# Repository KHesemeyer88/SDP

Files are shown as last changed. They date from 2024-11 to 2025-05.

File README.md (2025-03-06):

# SDP
Everyone has their own branch. 
You only work in your own branch.
Main only gets updated once a week and requires approval.
To collaborate in between, merge with your collaborator's branch back and forth.
To change branches: git checkout main, git checkout origin/YourBranch, etc.
To merge changes your collaborator made: git merge origin/CollaboratorBranch, etc.
  -Then resolve any merge conflicts, sync changes.

To get yourself up to date with main:
  -git checkout main
  -git pull
  -git checkout origin/YourBranch
  -git merge main

To merge person A to person B
-person A has updates / new code

In old/out_of_date branch

git merge the_branch_with_updates

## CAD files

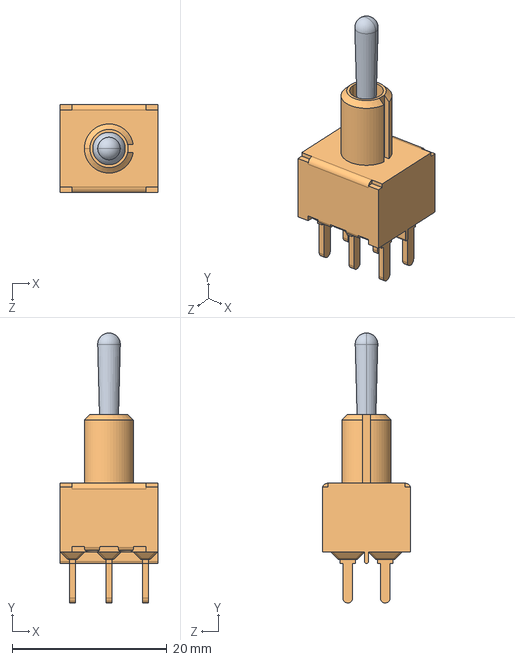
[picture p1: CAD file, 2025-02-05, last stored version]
powerDistribution/100DP3T1B1M2QEH.step
12.7 x 34.9 x 11.4 mm

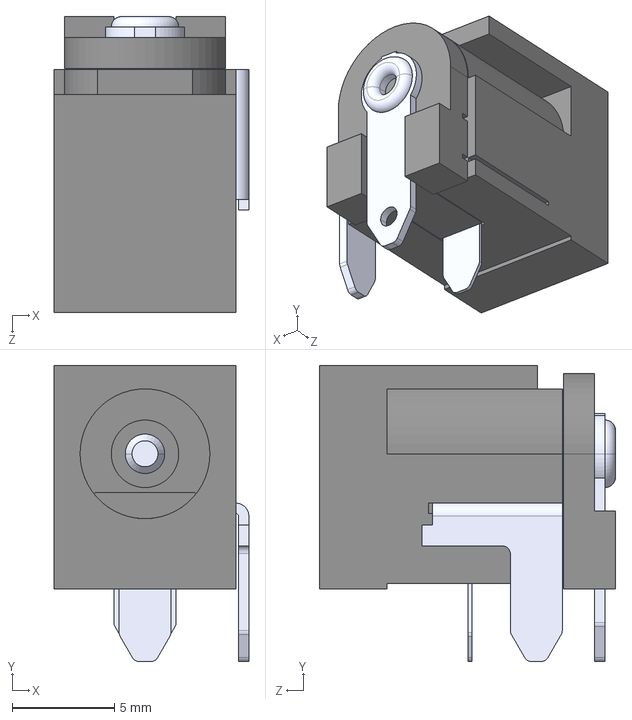
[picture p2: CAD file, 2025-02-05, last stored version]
powerDistribution/RAPC722X.step
9.53 x 14.5 x 14.5 mm

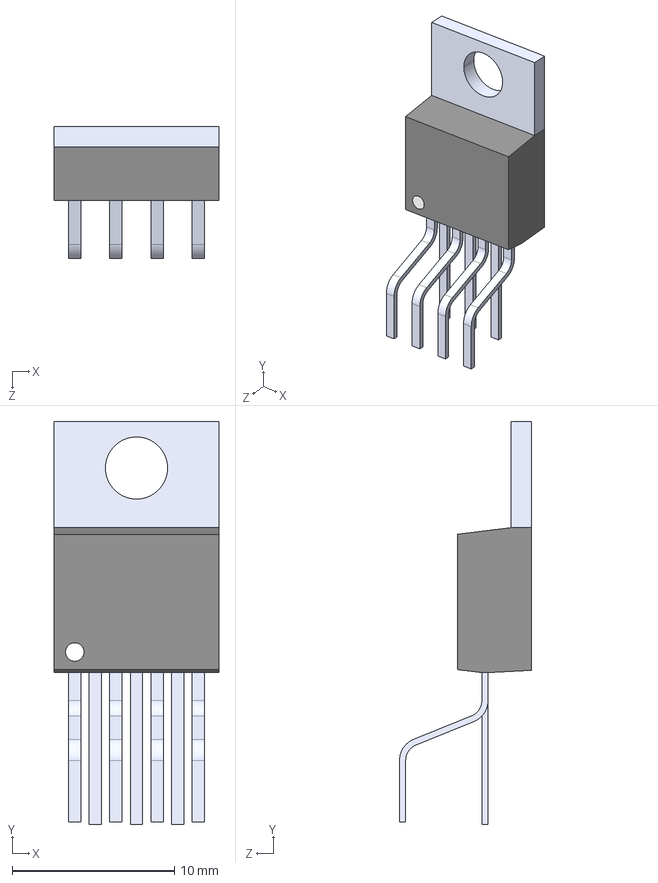
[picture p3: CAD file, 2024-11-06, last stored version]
powerDistribution/LM2678T-ADJ_NOPB.step
10.2 x 24.9 x 8.14 mm

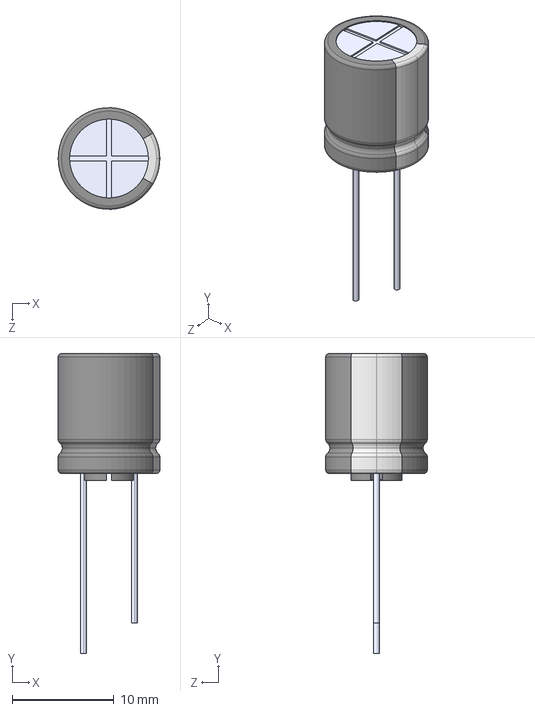
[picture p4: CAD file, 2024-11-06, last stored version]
powerDistribution/EEUFC1H101.step
10.0 x 29.5 x 9.99 mm

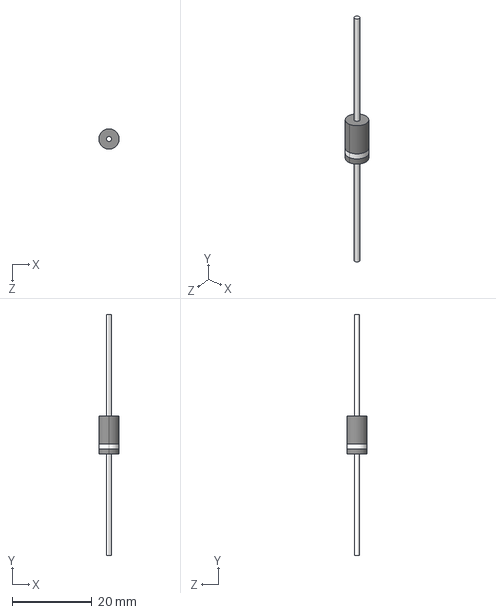
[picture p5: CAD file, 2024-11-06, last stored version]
powerDistribution/1N5822.step
5.08 x 60.3 x 5.08 mm

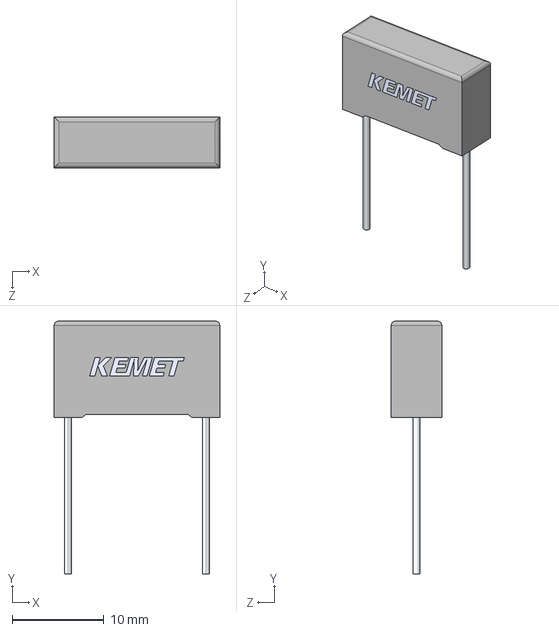
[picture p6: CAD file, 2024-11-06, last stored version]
powerDistribution/CFR_RB2_18X10.5X5.5_L18H10.5T5.5S15LL17F0.8.step
18.0 x 27.5 x 5.50 mm

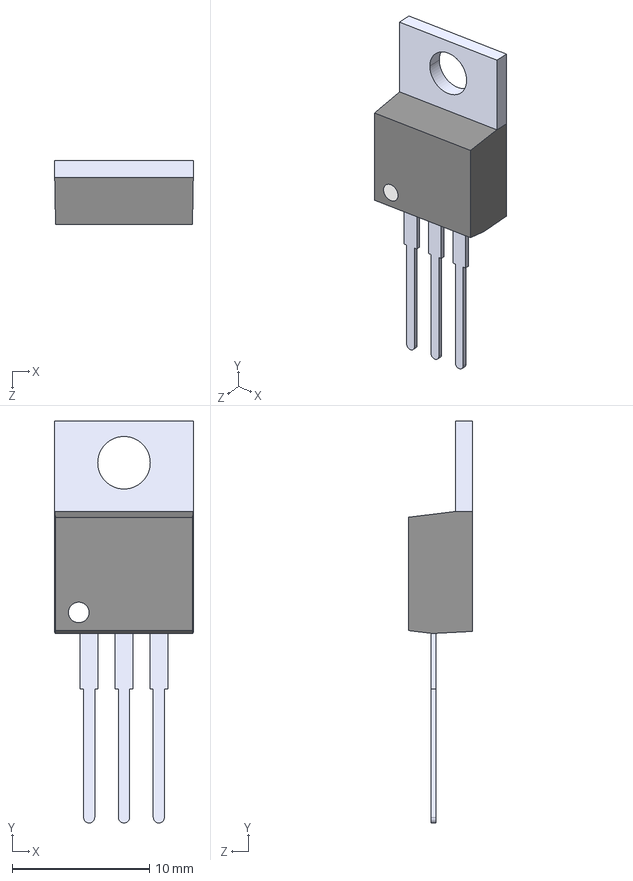
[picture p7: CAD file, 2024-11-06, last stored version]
powerDistribution/LM338T.step
10.2 x 29.3 x 4.70 mm

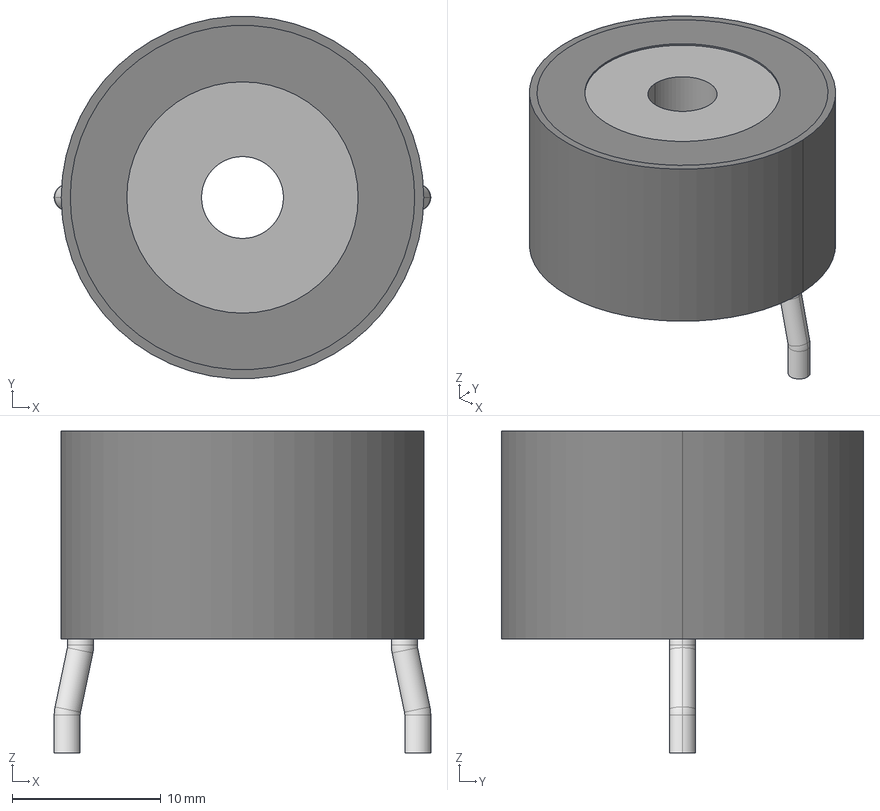
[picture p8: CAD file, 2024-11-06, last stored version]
powerDistribution/1410454C_MUR.step
25.4 x 24.4 x 21.7 mm

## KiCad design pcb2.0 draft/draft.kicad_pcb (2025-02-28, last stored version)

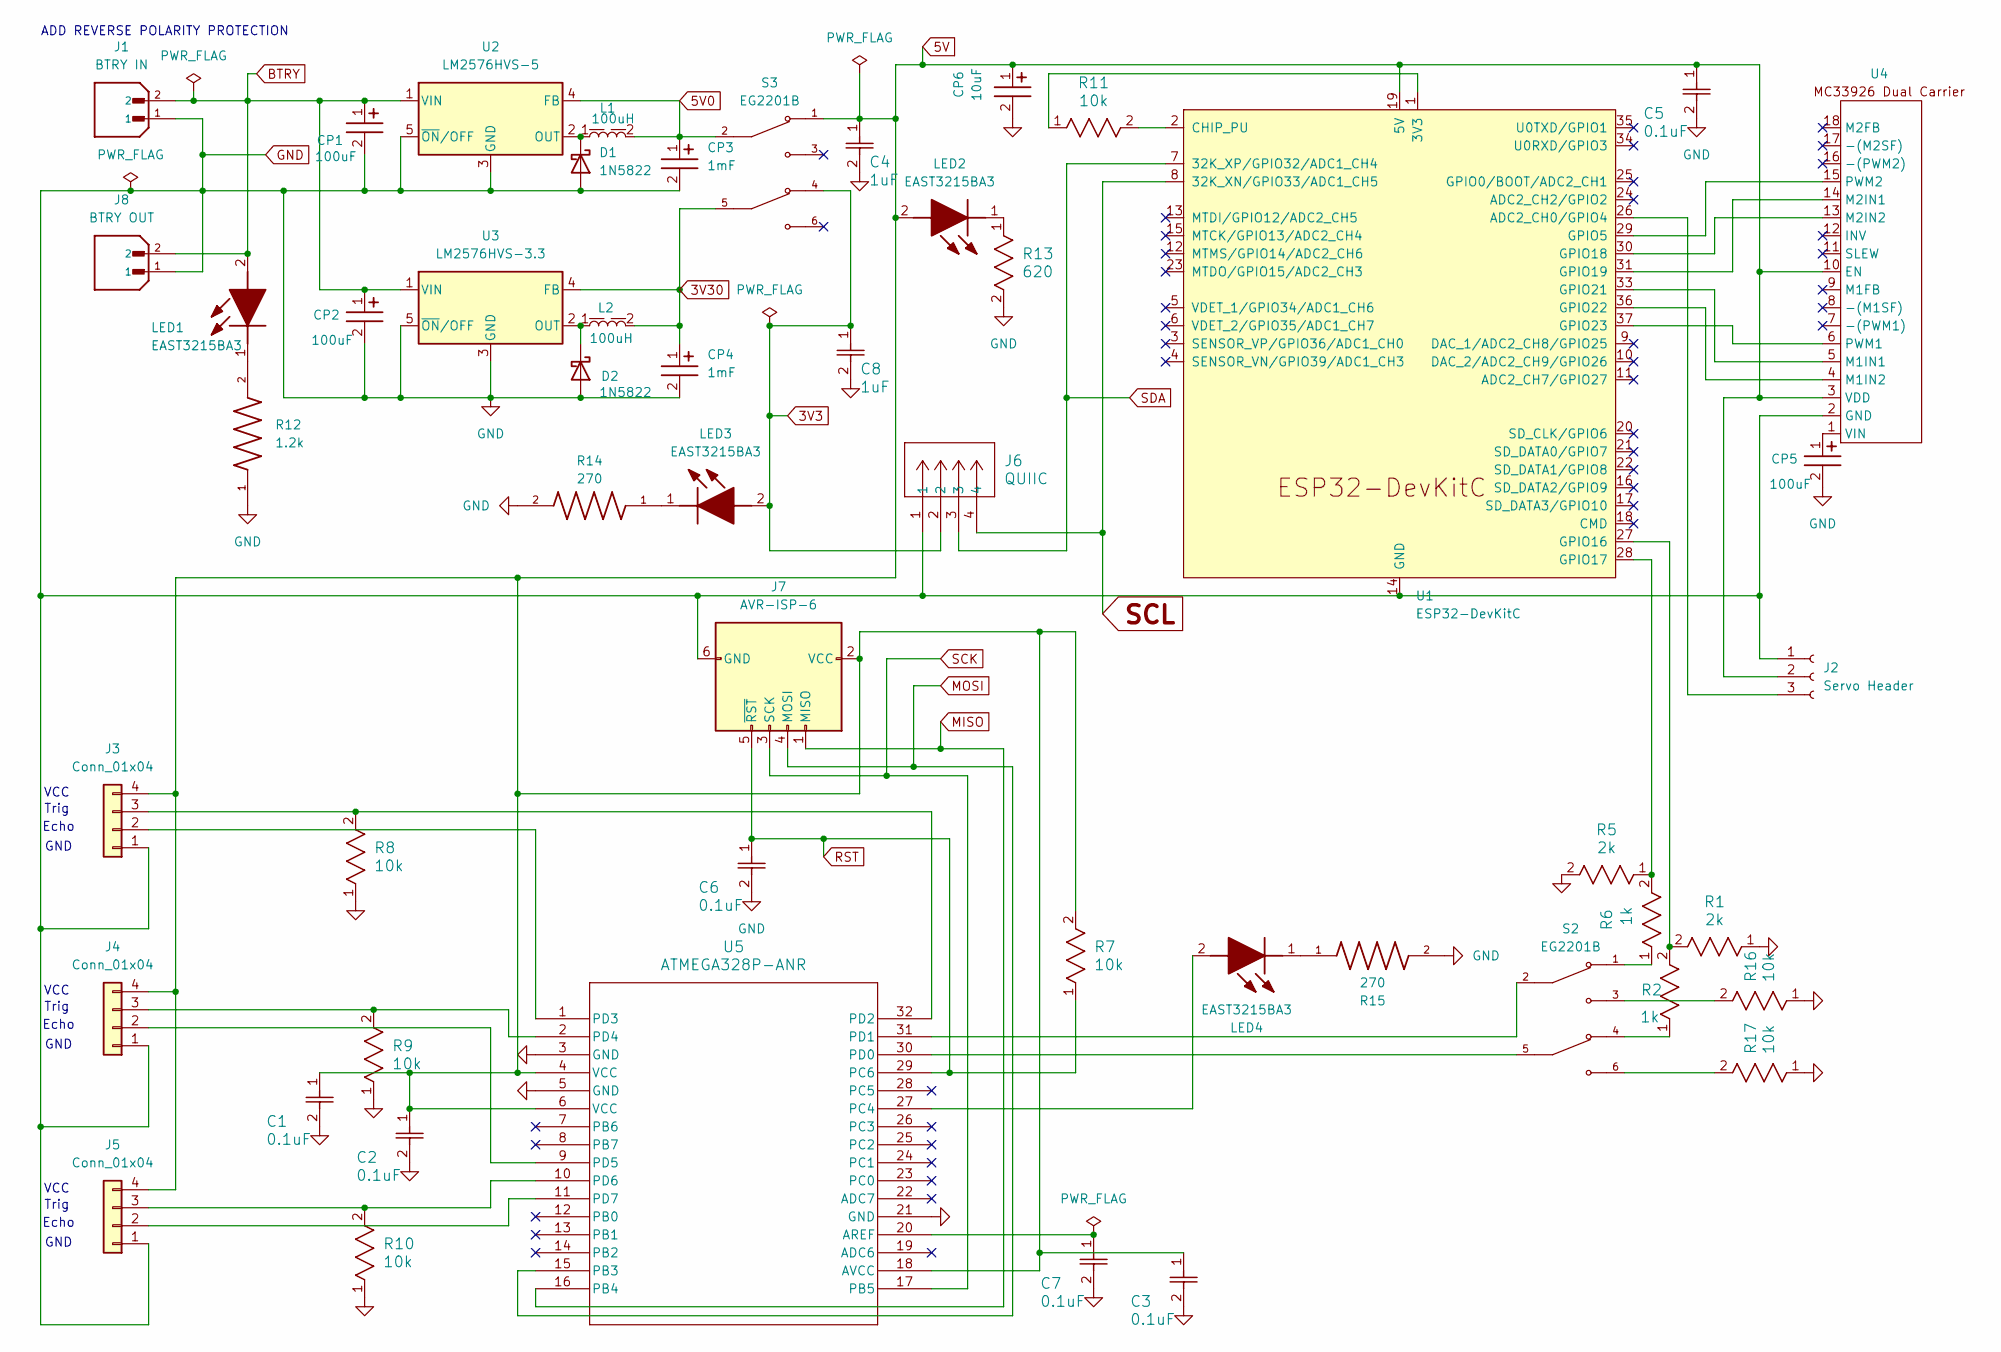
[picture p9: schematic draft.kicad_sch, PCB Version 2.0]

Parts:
C1, C2, C3, C5, C6, C7: 0.1uF; G-188_MUR-L
C4, C8: 1uF; CAP_GRM21_MUR-L
CP1, CP2, CP5: 100uF; CP_Wurth_WCAP-PSLP-D5L5.5; Part Number 875105242010
CP3, CP4: 1mF; CP_Wurth_WCAP-ASLI-D12.5L14; Part Number 865080462016
CP6: 10uF; CP_Wurth_WCAP-PSLP-D5L5.8; Part Number 875105359001
D1, D2: 1N5822; D_DO-201AD_P15.24mm_Horizontal
J1: BTRY IN; JST_B2B-XH-A; PARTREV N/A
J2: Servo Header; PinSocket_1x03_P2.54mm_Vertical
J3, J4, J5: Conn_01x04; PinHeader_1x04_P2.54mm_Vertical
J6: QUIIC; CONN_SM04B-SRSS-TB_JST
J7: AVR-ISP-6; IDC-Header_2x03_P2.54mm_Vertical
J8: BTRY OUT; JST_B2B-XH-A; PARTREV N/A
L1, L2: 100uH; L_Wurth_WE-PD-1245; Part Number 7447715101
LED1, LED2, LED3, LED4: EAST3215BA3; LEDC3215X110N; Mouser Part Number 638-EAST3215BA3
R1, R5: 2k; RES_CR0805_VEN-L
R2, R6: 1k; RES_CR0805_VEN-L
R7, R8, R9, R10, R11, R16, R17: 10k; RES_CR0805_VEN-L
R12: 1.2k; RES_ERJU08J122V; PARTREV 3/1/2020
R13: 620; RC1206N_PAN-L
R14, R15: 270; RES_ERJU08J271V; PARTREV 3/1/2020
S2, S3: EG2201B; SW_EG2201B; PARTREV C
U1: ESP32-DevKitC
U2: LM2576HVS-5; TO-263-5_TabPin3
U3: LM2576HVS-3.3; TO-263-5_TabPin3
U4: polulu_MC33926_dual
U5: ATMEGA328P-ANR; 32A_ATM-L

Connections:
3V3: C8.1, J6.2, LED3.2 (A), S3.4
3V30: CP4.1, L2.2, S3.5, U3.4 (FB)
5V: C1.1, C2.1, C3.1, C4.1, C5.1, CP6.1, J2.2, J3.4, J4.4, J5.4, J7.2 (VCC), LED2.2 (A), R7.2, S3.1, U1.19 (5V), U4.3 (VDD), U4.10 (EN), U5.4 (VCC), U5.6 (VCC), U5.18 (AVCC)
5V0: CP3.1, L1.2, S3.2, U2.4 (FB)
BTRY: CP1.1, CP2.1, J1.2, J8.2, LED1.2 (A), U2.1 (VIN), U3.1 (VIN)
GND: C1.2, C2.2, C3.2, C4.2, C5.2, C6.2, C7.2, C8.2, CP1.2, CP2.2, CP3.2, CP4.2, CP5.2, CP6.2, D1.2 (A), D2.2 (A), J1.1, J2.1, J3.1, J4.1, J5.1, J6.1, J7.6 (GND), J8.1, R1.1, R5.2, R8.1, R9.1, R10.1, R12.1, R13.2, R14.2, R15.2, R16.1, R17.1, U1.14 (GND), U1.32 (GND), U1.38 (GND), U2.3 (GND), U2.5 (~ON/OFF), U3.3 (GND), U3.5 (~ON/OFF), U4.2 (GND), U5.3 (GND), U5.5 (GND), U5.21 (GND)
MISO: J7.1 (MISO), U5.16 (PB4)
MOSI: J7.4 (MOSI), U5.15 (PB3)
unnamed: D1.1 (K), L1.1, U2.2 (OUT)
unnamed: D2.1 (K), L2.1, U3.2 (OUT)
unnamed: J2.3, U1.26 (ADC2_CH0/GPIO4)
unnamed: J3.2, U5.1 (PD3)
unnamed: J3.3, R8.2, U5.32 (PD2)
unnamed: J4.2, U5.9 (PD5)
unnamed: J4.3, R9.2, U5.2 (PD4)
unnamed: J5.2, U5.11 (PD7)
unnamed: J5.3, R10.2, U5.10 (PD6)
unnamed: LED1.1 (K), R12.2
unnamed: LED2.1 (K), R13.1
unnamed: LED3.1 (K), R14.1
unnamed: LED4.2 (A), U5.27 (PC4)
unnamed: LED4.1 (K), R15.1
unnamed: R2.1, S2.4
unnamed: R6.1, S2.1
unnamed: R16.2, S2.3
unnamed: R17.2, S2.6
unnamed: R11.1, U1.1 (3V3)
unnamed: R11.2, U1.2 (CHIP_PU)
unnamed: U1.29 (GPIO5), U4.15 (PWM2)
unnamed: R1.2, R2.2, U1.27 (GPIO16)
unnamed: R5.1, R6.2, U1.28 (GPIO17)
unnamed: U1.30 (GPIO18), U4.13 (M2IN2)
unnamed: U1.31 (GPIO19), U4.14 (M2IN1)
unnamed: U1.33 (GPIO21), U4.5 (M1IN1)
unnamed: U1.36 (GPIO22), U4.4 (M1IN2)
unnamed: U1.37 (GPIO23), U4.6 (PWM1)
unnamed: CP5.1, U4.1 (VIN)
unnamed: C7.1, U5.20 (AREF)
unnamed: S2.5, U5.30 (PD0)
unnamed: S2.2, U5.31 (PD1)
RST: C6.1, J7.5 (~RST), R7.1, U5.29 (PC6)
SCK: J7.3 (SCK), U5.17 (PB5)
SCL: J6.4, U1.8 (32K_XN/GPIO33/ADC1_CH5)
SDA: J6.3, U1.7 (32K_XP/GPIO32/ADC1_CH4)

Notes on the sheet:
GND
Echo
VCC
Trig
ADD REVERSE POLARITY PROTECTION

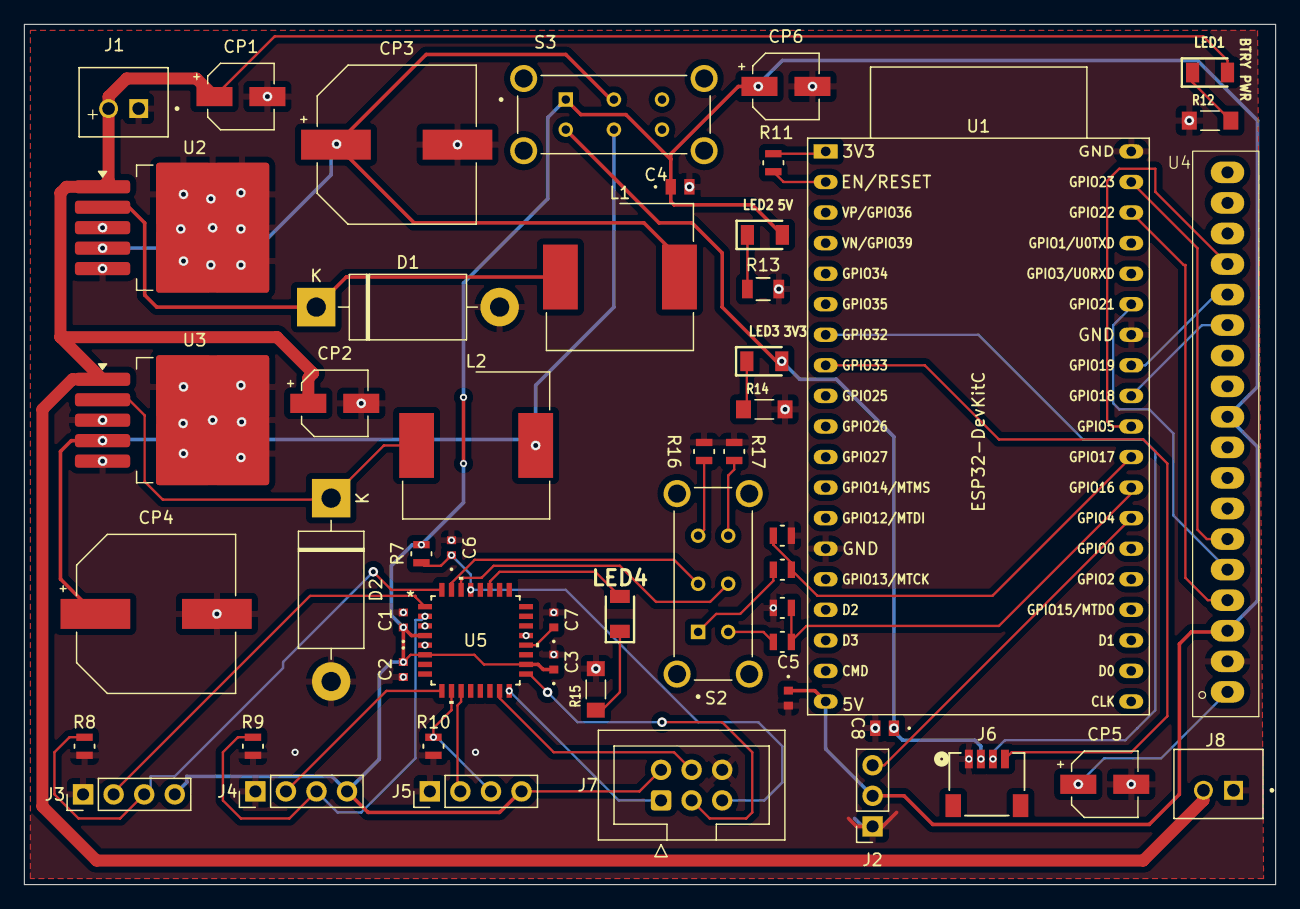
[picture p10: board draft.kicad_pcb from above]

Board: 2 copper layers, 104.0 x 71.5 mm, 52 parts (0 on the bottom side), 44 nets.

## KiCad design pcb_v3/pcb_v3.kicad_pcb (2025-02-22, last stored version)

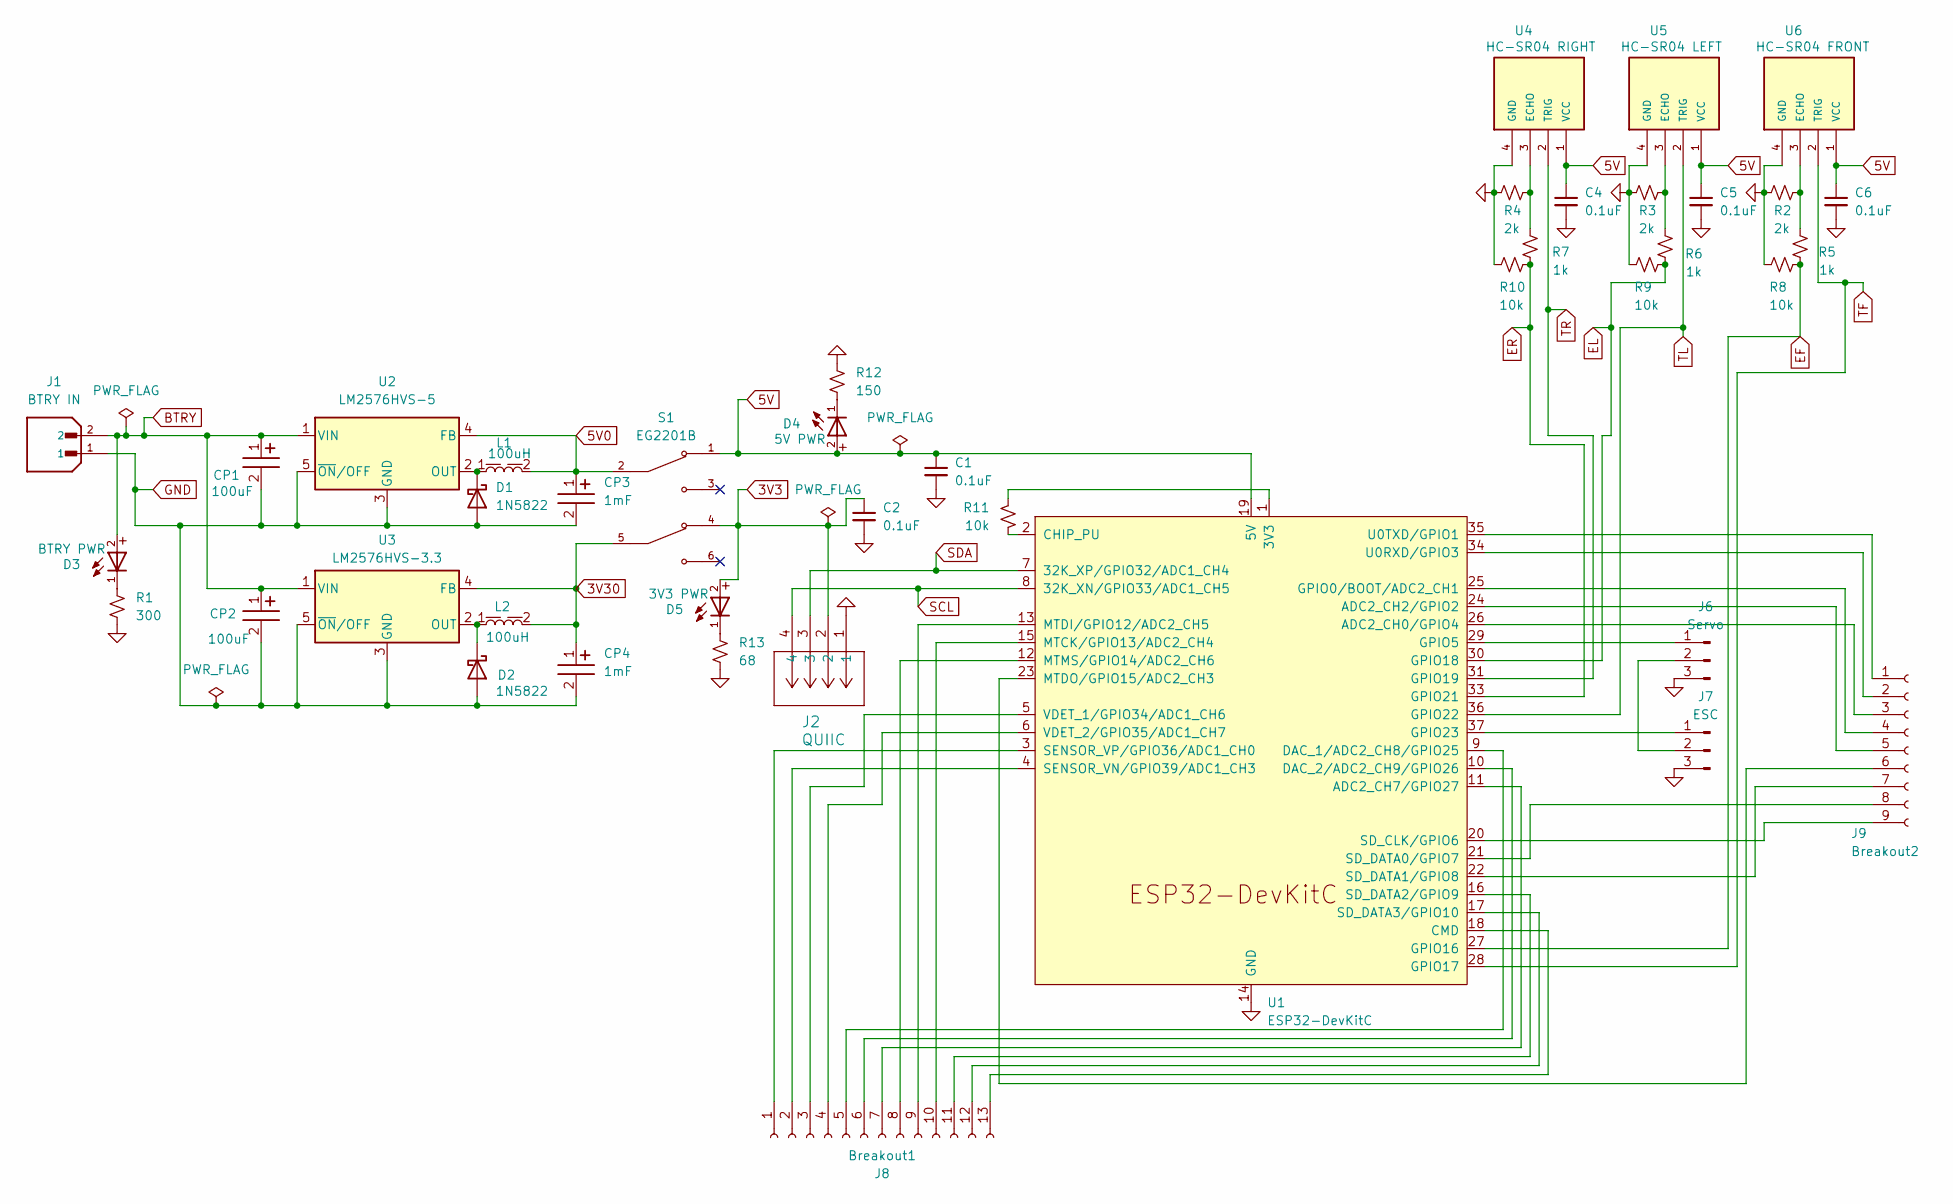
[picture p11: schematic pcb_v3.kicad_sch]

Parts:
C1, C2, C4, C5, C6: 0.1uF; C_1206_3216Metric_Pad1.33x1.80mm_HandSolder
CP1, CP2: 100uF; CP_Wurth_WCAP-PSLP-D5L5.5; Part Number 875105242010
CP3, CP4: 1mF; CP_Wurth_WCAP-ASLI-D12.5L14; Part Number 865080462016
D1, D2: 1N5822; D_DO-201AD_P15.24mm_Horizontal
D3: BTRY PWR; WL-SMSW_3014_LED
D4: 5V PWR; WL-SMSW_3014_LED
D5: 3V3 PWR; WL-SMSW_3014_LED
J1: BTRY IN; JST_B2B-XH-A; PARTREV N/A
J2: QUIIC; CONN_SM04B-SRSS-TB_JST
J6: Servo; JST_XH_B3B-XH-A_1x03_P2.50mm_Vertical
J7: ESC; JST_XH_B3B-XH-A_1x03_P2.50mm_Vertical
J8: Breakout1; PinSocket_1x13_P2.54mm_Vertical
J9: Breakout2; PinSocket_1x09_P2.54mm_Vertical
L1, L2: 100uH; L_Wurth_WE-PD-1245; Part Number 7447715101
R1: 300; R_1206_3216Metric_Pad1.30x1.75mm_HandSolder
R2, R3, R4: 2k; R_1206_3216Metric_Pad1.30x1.75mm_HandSolder
R5, R6, R7: 1k; R_1206_3216Metric_Pad1.30x1.75mm_HandSolder
R8, R9, R10, R11: 10k; R_1206_3216Metric_Pad1.30x1.75mm_HandSolder
R12: 150; R_1206_3216Metric_Pad1.30x1.75mm_HandSolder
R13: 68; R_1206_3216Metric_Pad1.30x1.75mm_HandSolder
S1: EG2201B; SW_EG2201B; PARTREV C
U1: ESP32-DevKitC
U2: LM2576HVS-5; TO-263-5_TabPin3
U3: LM2576HVS-3.3; TO-263-5_TabPin3
U4: HC-SR04 RIGHT; XCVR_HC-SR04
U5: HC-SR04 LEFT; XCVR_HC-SR04
U6: HC-SR04 FRONT; XCVR_HC-SR04

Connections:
3V3: C2.1, D5.2, J2.2, S1.4
3V30: CP4.1, L2.2, S1.5, U3.4 (FB)
5V: C1.1, C4.1, C5.1, C6.1, D4.2, S1.1, U1.19 (5V), U4.1 (VCC), U5.1 (VCC), U6.1 (VCC)
5V0: CP3.1, L1.2, S1.2, U2.4 (FB)
BTRY: CP1.1, CP2.1, D3.2, J1.2, U2.1 (VIN), U3.1 (VIN)
EF: R5.2, R8.1, U1.27 (GPIO16)
EL: R6.2, R9.1, U1.30 (GPIO18)
ER: R7.2, R10.1, U1.33 (GPIO21)
GND: C1.2, C2.2, C4.2, C5.2, C6.2, CP1.2, CP2.2, CP3.2, CP4.2, D1.2 (A), D2.2 (A), J1.1, J2.1, J6.3, J7.3, R1.2, R2.2, R3.2, R4.2, R8.2, R9.2, R10.2, R12.2, R13.2, U1.14 (GND), U1.32 (GND), U1.38 (GND), U2.3 (GND), U2.5 (~ON/OFF), U3.3 (GND), U3.5 (~ON/OFF), U4.4 (GND), U5.4 (GND), U6.4 (GND)
unnamed: D1.1 (K), L1.1, U2.2 (OUT)
unnamed: D2.1 (K), L2.1, U3.2 (OUT)
unnamed: D3.1, R1.1
unnamed: D4.1, R12.1
unnamed: D5.1, R13.1
unnamed: J6.1, U1.29 (GPIO5)
unnamed: J6.2, J7.2
unnamed: J7.1, U1.37 (GPIO23)
unnamed: J8.1, U1.3 (SENSOR_VP/GPIO36/ADC1_CH0)
unnamed: J8.2, U1.4 (SENSOR_VN/GPIO39/ADC1_CH3)
unnamed: J8.3, U1.5 (VDET_1/GPIO34/ADC1_CH6)
unnamed: J8.4, U1.6 (VDET_2/GPIO35/ADC1_CH7)
unnamed: J8.5, U1.9 (DAC_1/ADC2_CH8/GPIO25)
unnamed: J8.6, U1.10 (DAC_2/ADC2_CH9/GPIO26)
unnamed: J8.7, U1.11 (ADC2_CH7/GPIO27)
unnamed: J8.8, U1.12 (MTMS/GPIO14/ADC2_CH6)
unnamed: J8.9, U1.13 (MTDI/GPIO12/ADC2_CH5)
unnamed: J8.10, U1.15 (MTCK/GPIO13/ADC2_CH4)
unnamed: J8.11, U1.16 (SD_DATA2/GPIO9)
unnamed: J8.12, U1.17 (SD_DATA3/GPIO10)
unnamed: J8.13, U1.18 (CMD)
unnamed: J9.1, U1.35 (U0TXD/GPIO1)
unnamed: J9.2, U1.34 (U0RXD/GPIO3)
unnamed: J9.3, U1.26 (ADC2_CH0/GPIO4)
unnamed: J9.4, U1.25 (GPIO0/BOOT/ADC2_CH1)
unnamed: J9.5, U1.24 (ADC2_CH2/GPIO2)
unnamed: J9.6, U1.23 (MTDO/GPIO15/ADC2_CH3)
unnamed: J9.7, U1.22 (SD_DATA1/GPIO8)
unnamed: J9.8, U1.21 (SD_DATA0/GPIO7)
unnamed: J9.9, U1.20 (SD_CLK/GPIO6)
unnamed: R11.1, U1.1 (3V3)
unnamed: R11.2, U1.2 (CHIP_PU)
unnamed: R4.1, R7.1, U4.3 (ECHO)
unnamed: R3.1, R6.1, U5.3 (ECHO)
unnamed: R2.1, R5.1, U6.3 (ECHO)
SCL: J2.4, U1.8 (32K_XN/GPIO33/ADC1_CH5)
SDA: J2.3, U1.7 (32K_XP/GPIO32/ADC1_CH4)
TF: U1.28 (GPIO17), U6.2 (TRIG)
TL: U1.36 (GPIO22), U5.2 (TRIG)
TR: U1.31 (GPIO19), U4.2 (TRIG)

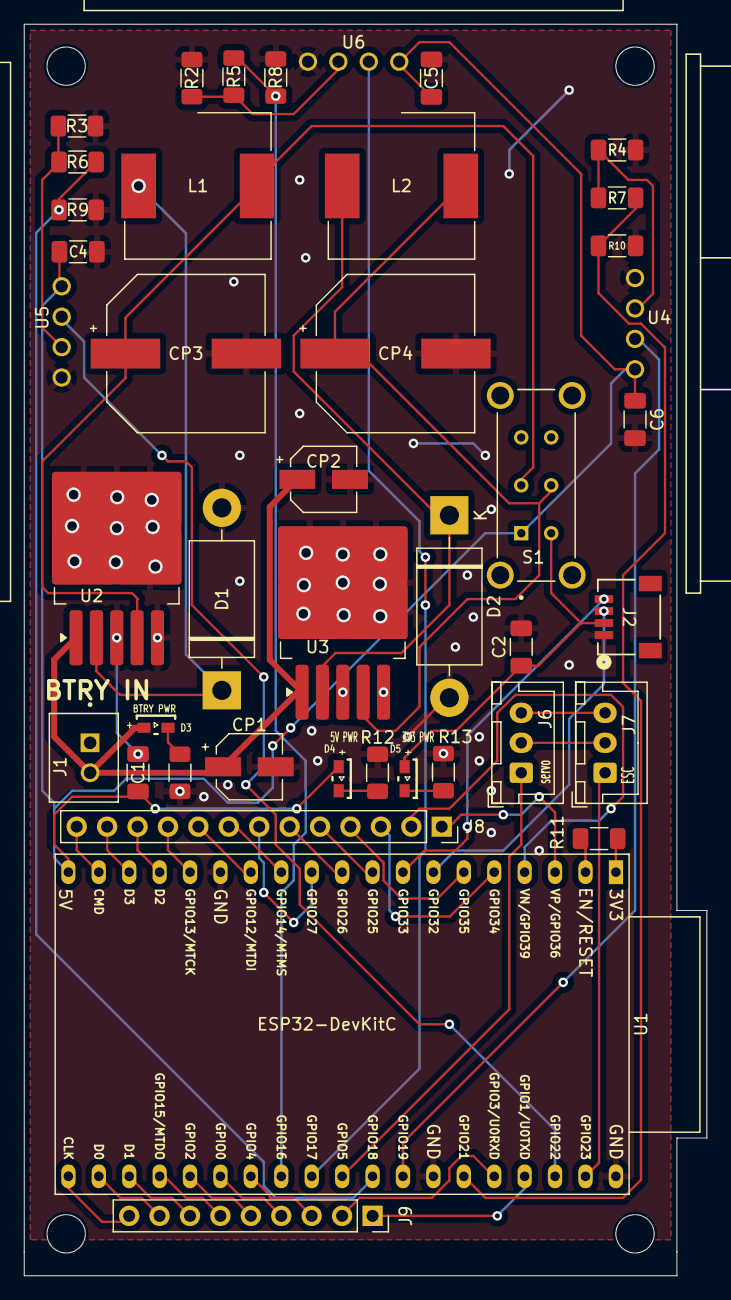
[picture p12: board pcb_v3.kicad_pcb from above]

Board: 2 copper layers, 57.0 x 104.5 mm, 42 parts (0 on the bottom side), 49 nets.

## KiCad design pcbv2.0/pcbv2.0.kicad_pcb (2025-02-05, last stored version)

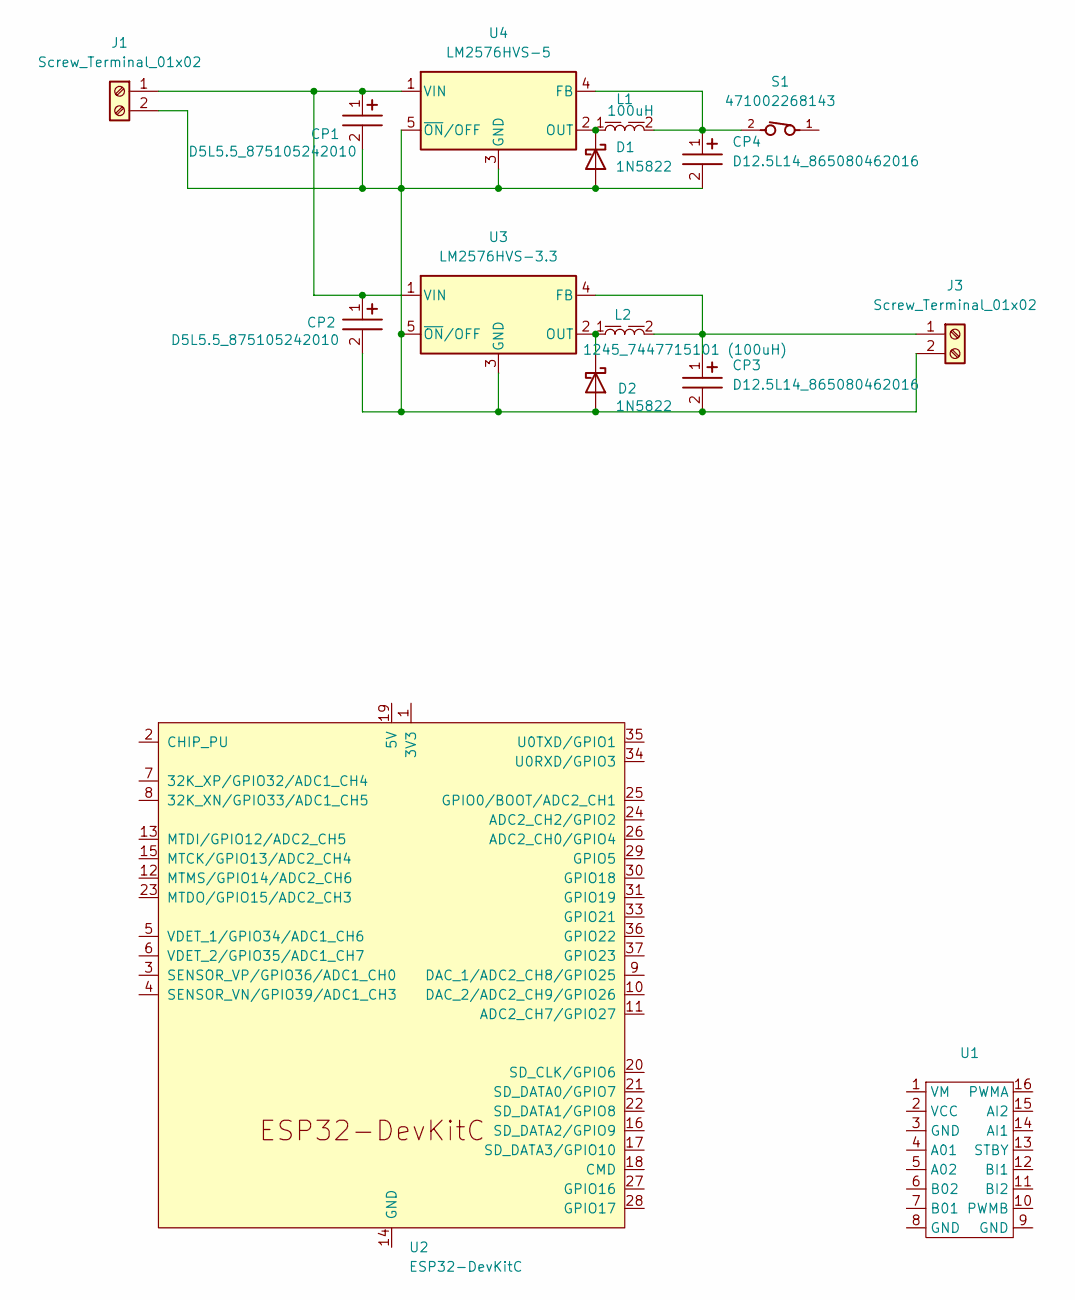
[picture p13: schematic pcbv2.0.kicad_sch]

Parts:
CP1, CP2: D5L5.5_875105242010; CP_Wurth_WCAP-PSLP-D5L5.5; Part Number 875105242010
CP3, CP4: D12.5L14_865080462016; CP_Wurth_WCAP-ASLI-D12.5L14; Part Number 865080462016
D1, D2: 1N5822; D_DO-201AD_P15.24mm_Horizontal
J1, J3: Screw_Terminal_01x02; CUI_TB002-500-02BE
L1: 100uH; L_Wurth_WE-PD-1245; Part Number 7447715101
L2: 1245_7447715101 (100uH); L_Wurth_WE-PD-1245; Part Number 7447715101
S1: 471002268143; switch_471002268143_actual; PART-NUMBER 471002268143
U1: TB6612FNG_BoB
U2: ESP32-DevKitC
U3: LM2576HVS-3.3; TO-263-5_TabPin3
U4: LM2576HVS-5; TO-263-5_TabPin3

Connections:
unnamed: CP1.2, CP2.2, CP3.2, CP4.2, D1.2 (A), D2.2 (A), J1.2, J3.2, U3.3 (GND), U3.5 (~ON/OFF), U4.3 (GND), U4.5 (~ON/OFF)
unnamed: D1.1 (K), L1.1, U4.2 (OUT)
unnamed: D2.1 (K), L2.1, U3.2 (OUT)
unnamed: CP1.1, CP2.1, J1.1, U3.1 (VIN), U4.1 (VIN)
unnamed: CP3.1, J3.1, L2.2, U3.4 (FB)
unnamed: U2.14 (GND), U2.32 (GND), U2.38 (GND)
unnamed: CP4.1, L1.2, S1.2, U4.4 (FB)

Board: 2 copper layers, 15 parts (0 on the bottom side), 7 nets, no tracks yet.

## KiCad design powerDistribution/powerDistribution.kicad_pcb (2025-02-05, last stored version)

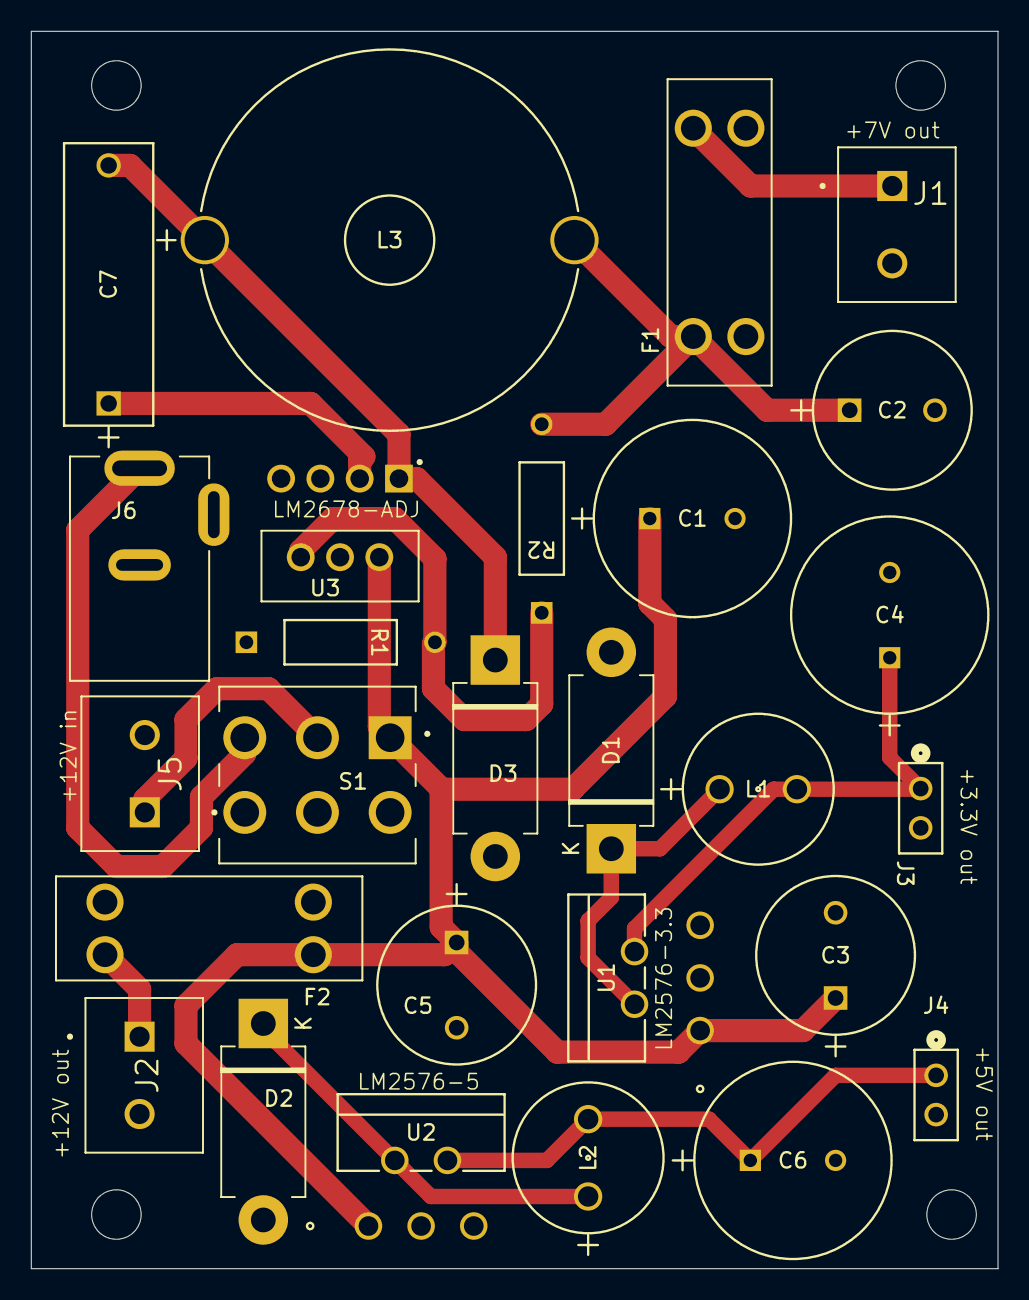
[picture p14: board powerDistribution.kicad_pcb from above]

Board: 2 copper layers, 62.5 x 80.0 mm, 27 parts (0 on the bottom side), 14 nets.

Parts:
C1, C4, C6: 1mF; CAP_12.5 X 25_NCH
C2: 220uF; PCAP_10x16-THRU-ELECT_NCA
C3, C5: 100uF; PCAP_10x16-THRU-ELECT_NCA
C7: 0.01uF; PHE-BD_KEM
D1, D2: 1N5822; D_DO-201AD_P12.70mm_Horizontal
D3: 1N5825; D_DO-201AD_P12.70mm_Horizontal
F1, F2: 3557-10; fz_holder_3557-10
J1, J2, J5: Screw_Terminal_01x02; CUI_TB002-500-02BE
J3, J4: Conn_01x02_Socket; CONN_PPPC021_SUL
J6: RAPC722X; SWITCHCRAFT_RAPC722X
L1, L2: 100uH; inductor_1A_100uH
L3: 22uH; 1422311C_MUR
R1: 1k; STA_RNF14_STP
R2: 4.9k; STA_RNF14_STP
S1: 100DP3T1B1M2QEH; SW_100DP3T1B1M2QEH
U1: LM2576-3.3; 3.3V_lm2576
U2: LM2576HVT-5; 5V_lm2576
U3: LM2678T; TO127P1041X469X2199-7N

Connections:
+12V: C1.1, C3.1, C5.1, F2.1_1, S1.1, U1.1 (VIN), U2.1 (VIN), U3.2 (INPUT)
/CHG12V: J6.PIN, S1.3
/Vout_3.3V: C4.1, J3.1, L1.2, U1.4 (FB)
/Vout_5V: C6.1, J4.1, L2.2, U2.4 (FB)
/Vout_7V: C2.1, F1.1_1, L3.2, R2.2
/Vout_7V_brk: F1.2_1, J1.1
/Vout_12V: F2.2_1, J2.1
GND: C1.2, C2.2, C3.2, C4.2, C5.2, C6.2, D1.2 (A), D2.2 (A), D3.2 (A), J1.2, J2.2, J3.2, J4.2, J5.2, J6.SLEEVE, R1.1, S1.4, S1.5, S1.6, U1.3 (GND), U1.5 (~ON/OFF), U2.3 (GND), U2.5 (~ON/OFF), U3.4 (GND)
unnamed: D1.1 (K), L1.1, U1.2 (OUT)
unnamed: D2.1 (K), L2.1, U2.2 (OUT)
unnamed: C7.2, D3.1 (K), L3.1, U3.1 (SWITCH_OUTPUT)
unnamed: J5.1, S1.2
unnamed: C7.1, U3.3 (CB)
unnamed: R1.2, R2.1, U3.6 (FB)

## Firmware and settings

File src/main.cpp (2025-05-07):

#include <Arduino.h>
#include "config.h"
#include "rtos_tasks.h"
#include "http_server.h"
#include <WiFi.h>
#include "logging.h"
#include "navigation.h"
#include "websocket_handler.h"
#include "SPIFFS.h"

// Definition for ntripClient (declared as extern in config.h)
WiFiClient ntripClient;

// Definition for ntripClient mutex (declared as extern in config.h)
SemaphoreHandle_t ntripClientMutex = NULL;

const char* logLevelToString(LogLevel level);

void setup() {
    Serial.begin(115200);
    delay(1000);
    Serial.printf("\n");
    Serial.printf("\n");
    Serial.printf("\n\nRC Car starting up with FreeRTOS...");
    Serial.printf("\n");
    
    

    //LOG_ERROR("SYSTEM RESTART DETECTED - this message should appear only once after power-up");
    
    // Connect to WiFi
    Serial.printf("Connecting to WiFi network: %s\n", ssid);
    Serial.printf("\n");
    //LOG_DEBUG("Connecting to WiFi network: %s", ssid);
    WiFi.begin(ssid, password);
    
    
    // Wait for connection with timeout
    while (WiFi.status() != WL_CONNECTED) {
        delay(500);
        Serial.print(".");
    }
    
    if (WiFi.status() == WL_CONNECTED) {
        char ipStr[16]; // Enough for IPv4: "xxx.xxx.xxx.xxx"
        snprintf(ipStr, sizeof(ipStr), "%u.%u.%u.%u",
            WiFi.localIP()[0], WiFi.localIP()[1],
            WiFi.localIP()[2], WiFi.localIP()[3]);
        Serial.printf("Connected to WiFi: %s, IP: %s\n\n", ssid, ipStr);
        Serial.println(WiFi.localIP());
        //LOG_DEBUG("Connected to WiFi: %s, IP: %s", ssid, ipStr);
    } else {
        Serial.printf("Failed to connect to WiFi. Will retry in RTOS tasks");
        Serial.printf("\n");
        //LOG_ERROR("Failed to connect to WiFi. Will retry in RTOS tasks");
    }
    
    // platformio -> quick access -> new terminal
    //pio run --target uploadfs
    // uploads data images to SPIFFS
    // SPIFFS is used for web pages and other static files
    if (!SPIFFS.begin(true)) {
        Serial.println("SPIFFS mount failed");
        return;
    }

    initWebSocket();

    if (!initNavigation()) {
        //LOG_ERROR("Failed to initialize navigation system");
    } else {
        //LOG_DEBUG("Navigation system initialized successfully");
    }
    
    // Initialize RTOS components
    LOG_DEBUG("currentLogLevel: %s", logLevelToString(currentLogLevel));
    delay(1000);
    Serial.printf("starting initRTOS");
    Serial.printf("\n");
    initRTOS();

    // Nothing else should run here - all code is now in tasks
    //LOG_DEBUG("Setup complete. RTOS scheduler taking over");
}

void loop() {
}

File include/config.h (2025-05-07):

#include <Arduino.h>
#include <ESP32Servo.h>
#include <WiFi.h>
#include <AsyncTCP.h>
#include <ESPAsyncWebServer.h>
#include <SparkFun_u-blox_GNSS_v3.h>
#include "base64.h" //Built-in ESP32 library
#include <WiFiClient.h>


// config.h
#ifndef CONFIG_H
#define CONFIG_H
// LIDAR pins
#define LIDAR_SDA_PIN 16
#define LIDAR_SCL_PIN 17
// SD Card SPI pins
#define SD_CS_PIN 18
#define SD_MISO_PIN 19
#define SD_SCK_PIN 21
#define SD_MOSI_PIN 22
#define SD_CD_PIN 25
#define SD_FREQUENCY 20000000  // 20 MHz SPI frequency for SD card
// Navigation board SPI pins
#define NAV_CS_PIN    15     // Chip Select (active low)
#define NAV_MOSI_PIN  13   // COPI (Controller Out, Peripheral In)
#define NAV_MISO_PIN  12   // CIPO (Controller In, Peripheral Out)
#define NAV_SCK_PIN   14    // SCLK (Serial Clock)
#define NAV_INT_PIN   26    // Interrupt pin
#define NAV_RST_PIN   27    // Reset pin
#define NAV_SPI_FREQUENCY 4000000  // 20 MHz SPI frequency - drop down if unstable

// Timing constants
#define COMMAND_TIMEOUT_MS          500
#define SONAR_UPDATE_INTERVAL       50
#define AVOIDANCE_MESSAGE_TIMEOUT   1000
#define DESTINATION_MESSAGE_TIMEOUT 5000
#define CONTROL_UPDATE_FREQUENCY    NAV_FREQ
#define NAV_UPDATE_FREQUENCY        NAV_FREQ


// WebSocket update intervals
const unsigned long WS_SENSOR_UPDATE_INTERVAL = 500;
const unsigned long WS_GPS_UPDATE_INTERVAL = 500;
const unsigned long WS_RTK_UPDATE_INTERVAL = 2000;
const unsigned long WS_STATS_UPDATE_INTERVAL = 500;

// Pin Definitions
const int STEERING_PIN = 5;   // GPIO5 for steering servo
const int ESC_PIN = 23;       // GPIO23 for ESC control

// Sonar thresholds (cm)
const int FRONT_STOP_THRESHOLD = 300; // in cm
//const int SIDE_AVOID_THRESHOLD = 50;

// Traxxas XL-2.5 ESC & servo values. Note ESC takes angles like a servo, but converts them to speed
const int ESC_NEUTRAL = 90;     // Neutral position (1.5ms pulse)
const int ESC_MAX_FWD = 150;    // Max forward allowed (180 removes speed governor)
const int ESC_MAX_REV = 50;     // Max reverse allowed (~1.1ms pulse)
const int ESC_MIN_FWD = 95;     // Minimum forward throttle
const int ESC_MIN_REV = 85;     // Minimum reverse throttle
const int STEERING_CENTER = 90;  // Center steering
const int STEERING_MAX = 65;     // Maximum steering angle deviation
const int TURN_ANGLE = 40;       // Angle to turn 
const int TRIM_ANGLE = 2;       //car lists left

// WiFi settings
// const char* ssid = "RC_Car_Control";
// const char* password = "12345678";
// Hotspot:
const char ssid[] = "pacercar";
const char password[] = "12345678";

// const char ssid[] = "Kians iPhone";
// const char password[] = "Dove'sHamster";

// const char ssid[] = "Galaxy XCover FieldPro8858";
// const char password[] = "bugo4303";

// const char ssid[] = "chewchewchew";
// const char password[] = "03092738Ss";

// MaCORS
const char casterHost[] = "macorsrtk.massdot.state.ma.us"; 
const char casterUser[] = "KHesemeyer88";
const char casterUserPW[] = "kN7?6jtG9YiNMgD@";
const uint16_t casterPort = 32000;
//const char mountPoint[] = "RTCM3MSM_MAGS"; // RTCM 3.2 MSM_MAXX(GNSS) MAGS (Amherst, but maybe change to MABT?)
//const char mountPoint[] = "RTCM3MSM_MABN"; // Colrain
const char mountPoint[] = "RTCM3MSM_MABT"; // Amherst

// Navigation constants
const float WAYPOINT_REACHED_RADIUS = 1.0; //meters
const int MAX_WAYPOINTS = 20;
const int NAV_FREQ = 20;

// Sonar filtering
const int FILTER_SAMPLES = 5;  // Number of samples to average

// Waypoint loop settings
//const int DEFAULT_LOOP_COUNT = 1;     // Default number of times to loop through waypoints
const float DEFAULT_TARGET_PACE = 1;  // Default target pace in m/s (0 = no pace control)
const float DEFAULT_TARGET_DISTANCE = 0; // Default target distance in meters (0 = no distance limit)

// Speed control values
const int SPEED_CORRECTION_INTERVAL = 200; // How often to adjust speed for pace (ms)
const float SPEED_CORRECTION_THRESHOLD = 0.05;  // How aggressively to correct speed (0-1)

// RTK Correction status tracking
enum CorrectionStatus {
  CORR_NONE,
  CORR_STALE,
  CORR_FRESH
};

// Function to handle system errors
void handleSystemError(const char* errorMsg, bool restartSystem);
void cleanupResources(bool cleanupMutexes, bool cleanupQueues, bool cleanupTasks);

extern WiFiClient ntripClient;

// Mutex for thread-safe access to ntripClient
extern SemaphoreHandle_t ntripClientMutex;

#endif // CONFIG_H

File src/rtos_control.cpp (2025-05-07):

#include "rtos_tasks.h"
#include "rtos_control.h"
#include "config.h"
#include <ESP32Servo.h>
#include "logging.h"
#include "navigation.h"
#include "gnss.h"
#include <PID_v1.h>
#include "obstacle.h"

// Control task variables
unsigned long lastCommandTime = 0;
bool drivingState = false;
unsigned long lastNonNeutralCommand = 0;
const unsigned long DRIVING_GRACE_PERIOD = 1500; // 1.5 seconds grace period


// For reverse handling
bool inReverseMode = false;
bool reverseSequenceActive = false;
unsigned long reverseSequenceStartTime = 0;
int reverseSequenceStep = 0;

// For PI control
static float cumulativeError = 0;
static int lastEscCommand = ESC_MIN_FWD;

// For resume navigation
static bool preObstacleActive = false;
static bool pathRecovery = false;
static float originalBearing = 0;

// Servo objects
extern Servo steeringServo;
extern Servo escServo;

// PID control variables
double pidInput = 0;     // GNSS speed in m/s
double pidSetpoint = 0;  // targetPace in m/s
double pidOutput = 0;    // throttle signal to ESC

// For tracking navigation state changes for PID reset
static bool prevAutonomousMode = false;
static bool prevPausedState = false;
static int mutexWait = 50;

// Initial tuning values (adjust as needed)
double Kp = 2.0, Ki = 3.5, Kd = 1.0;

// PID controller instance (DIRECT means output increases when error is positive)
PID speedPID(&pidInput, &pidOutput, &pidSetpoint, Kp, Ki, Kd, DIRECT);

// Control task function
void ControlTask(void *pvParameters) {
    //LOG_DEBUG("ControlTask");
    ControlCommand currentCmd;
    TickType_t xLastWakeTime;
    const TickType_t xFrequency = pdMS_TO_TICKS(1000 / CONTROL_UPDATE_FREQUENCY);
    
    // Local variables for position, heading, target
    float currentLat, currentLon, currentSpeed, currentHeading;
    float targetLat, targetLon;
    bool autonomousActive, isPaused, followingWaypoints;
    speedPID.SetMode(AUTOMATIC);

    speedPID.SetOutputLimits(ESC_MIN_FWD, ESC_MAX_FWD);  // Safe range
    speedPID.SetSampleTime(1000 / CONTROL_UPDATE_FREQUENCY);  // Match task rate

    // Initialize time for consistent frequency
    xLastWakeTime = xTaskGetTickCount();
    
    // Task loop
    while (true) {
        unsigned long currentTime = millis();
        
        // Check for manual control commands
        if (xQueueReceive(commandQueue, &currentCmd, 0) == pdTRUE) {
            //LOG_DEBUG("Received command queue");
            // Process the command based on type
            if (currentCmd.type == CMD_MANUAL_CONTROL) {
                // Manual control command received
                //LOG_DEBUG("Manual control command received");
                // Update driving state and timestamp
                drivingState = currentCmd.manual.isDriving;
                if (drivingState) {
                    lastNonNeutralCommand = currentTime;
                }
                
                // Apply manual control if we're not in autonomous mode
                if (xSemaphoreTake(navDataMutex, pdMS_TO_TICKS(mutexWait)) == pdTRUE) {
                    // Check if we're in autonomous mode
                    //LOG_DEBUG("Checking if we're in autonomous mode");
                    autonomousActive = navStatus.autonomousMode;
                    xSemaphoreGive(navDataMutex);
                    
                    if (!autonomousActive) {
                        //LOG_DEBUG("Entering manual control in controlTask");
                        // Apply manual control commands to servos
                        if (xSemaphoreTake(servoMutex, pdMS_TO_TICKS(mutexWait)) == pdTRUE) {
                            //LOG_DEBUG("Received servoMutex");
                            // Map joystick to servo values
                            int steeringValue = STEERING_CENTER + (currentCmd.manual.steering * STEERING_MAX);
                            
                            // Apply steering limit
                            steeringValue = constrain(steeringValue, 
                                              STEERING_CENTER - STEERING_MAX, 
                                              STEERING_CENTER + STEERING_MAX);
                            
                           // Apply throttle based on joystick position
                            int throttleValue;
                            if (currentCmd.manual.throttle > 0) {
                                //LOG_DEBUG("Forward throttle value set");
                                // Forward
                                inReverseMode = false; // Exit reverse mode if forward requested
                                throttleValue = ESC_NEUTRAL + (currentCmd.manual.throttle * (ESC_MAX_FWD - ESC_NEUTRAL));
                            } else if (currentCmd.manual.throttle < 0) {
                                //LOG_DEBUG("Neg. throttle detected");
                                // Reverse - check if we need to start sequence
                                if (!inReverseMode && !reverseSequenceActive) {
                                    //LOG_DEBUG("Setting rev. sequence params");
                                    reverseSequenceActive = true;
                                    reverseSequenceStep = 0;
                                    reverseSequenceStartTime = currentTime;
                                    throttleValue = ESC_NEUTRAL; // Start with neutral
                                } else if (inReverseMode) {
                                    // Already in reverse mode, can apply reverse directly
                                    throttleValue = ESC_NEUTRAL + (currentCmd.manual.throttle * (ESC_NEUTRAL - ESC_MAX_REV));
                                    //LOG_DEBUG("Reverse mode active: throttle=%.2f, output=%d", currentCmd.manual.throttle, throttleValue);
                                } else {
                                    //LOG_DEBUG("Let sequence handler control throttle");
                                    // In middle of sequence, let sequence handler control throttle
                                    throttleValue = ESC_NEUTRAL;
                                }
                            } else {
                                //LOG_DEBUG("Neutral");
                                // Neutral
                                throttleValue = ESC_NEUTRAL;
                            }

                            // Apply servo commands (ESC only if not in reverse sequence)
                            steeringServo.write(steeringValue);
                            if (!reverseSequenceActive) {
                                //LOG_DEBUG("Throttle applied: %d", throttleValue);
                                escServo.write(throttleValue);
                            }
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

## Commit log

2024-11-06 Add power distribution board KiCad project files
    [1410454C_MUR.step, 1N5822.step, CFR_RB2_18X10.5X5.5_L18H10.5T5.5S15LL17F0.8.step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]
2024-12-02 current gnss position and heading txt file
2024-12-02 read arduino serial of current gnss reading
2025-02-05 brent's wifi_test_6
    [100DP3T1B1M2QEH.step, RAPC722X.step, powerDistribution.kicad_pcb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]
2025-02-10 completed draft of pcbv2 - in "draft" folder
    [draft.kicad_sch]
2025-02-10 some more schematic updates
    [draft.kicad_sch]
2025-02-11 completed pcb layout
    [draft-B_Cu.gbr, draft-B_Mask.gbr, draft-B_Paste.gbr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]
2025-02-17 added basic sonar (works but needs work)
2025-02-22 pcb version 3 complete
    [pcb_v3-B_Cu.gbr, pcb_v3-B_Mask.gbr, pcb_v3-B_Paste.gbr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]
2025-02-24 fixed sonar latching issue
2025-02-28 broke out code into header files
    [100DP3T1B1M2QEH.step, 1410454C_MUR.step, 1N5822.step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]
2025-02-28 created archive folder
    [100DP3T1B1M2QEH.step, 1410454C_MUR.step, 1N5822.step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]
2025-02-28 fixed psychotic pace behavior (hopefully)
    [config.h]
2025-02-28 seriously, fixed broken stuff
    [config.h]
2025-03-05 Timing improvements, global safety timeout fixed
    [config.h]
2025-03-06 fixed sonar updates not happening
2025-03-10 Fixed stright line phase, improved pace ctrl
    [100DP3T1B1M2QEH.step, 1410454C_MUR.step, 1N5822.step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]
2025-03-19 Cleaned up disastrous file structure
    [100DP3T1B1M2QEH.step, 1410454C_MUR.step, 1N5822.step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]
2025-03-21 fixed manual reverse bug
    [rtos_control.cpp]
2025-03-22 fixed system reset issue (don't use String!!!!!). Not yet field tested
    [gnss.cpp, http_server.cpp, logging.cpp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]
2025-03-26 updataed pin assignments in config for new board
2025-03-28 pin updates for nav SPI
2025-03-28 code currently broken, tried to implement SPI
    [gnss.cpp, main.cpp]
2025-03-30 changed SPI pin assignment
2025-03-30 first attempt at complete SPI integration
2025-03-31 solved new reboot issue, working on getting SPI comms with nav board
    [gnss.cpp, logging.cpp, main.cpp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]
2025-03-31 HOLY SHIT WORKING SPI
2025-04-02 4.86m/s achieved - car occasionally flips, need to refine steering and throttle controls
    [config.h, rtos_control.cpp]
2025-04-09 initial ws json to binary switch
2025-04-11 First attempt at PID library for throttle. Works well, but first startup is very slow.
2025-04-16 This version works but steering seems wild, maybe becuase of weather?
2025-04-16 good steering control, good field test in quad
2025-04-21 dropped left/right obst from manual page, playing with PID params
2025-04-21 THE BEST OBSTACLE AVOIDANCE. Pace control is not going to work without anti-windup logic
    [config.h, obstacle.cpp, rtos_control.cpp]
2025-05-02 add delay before sd.begin, no fix
    [logging.cpp]
2025-05-02 moved sd init after http begin, no fix
    [http_server.cpp, main.cpp]
2025-05-02 added delay before sd init, after https init (which i should have done eariler) pretty sure that fixed it. Also added manual SD card reboot. Added marcus loop image back. Still some small webpage pro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
    [http_server.cpp, main.cpp]

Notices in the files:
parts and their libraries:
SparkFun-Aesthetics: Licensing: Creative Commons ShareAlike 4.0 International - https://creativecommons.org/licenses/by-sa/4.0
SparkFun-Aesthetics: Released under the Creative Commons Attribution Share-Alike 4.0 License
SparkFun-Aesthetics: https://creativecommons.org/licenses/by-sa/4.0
